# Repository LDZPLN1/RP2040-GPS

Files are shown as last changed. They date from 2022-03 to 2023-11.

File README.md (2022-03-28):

Adafruit Feather RP2040 GPS

Adafruit Feather RP2040 GPS (For HAM Radio)

UTC and local clock is set via GPS data.  Software then calculates the current Maidenhead Grid location.

DST is automatically calculated for local timezone.

Designed to get time/date/lat/lon/grid/compass direction without any internet access as a stand alone device.

ADAFRUIT FEATHER RP2040<br>
BN-880 GPS WITH MAGNETOMETER - USES U-BLOX 8 SERIES CHIPSET<br>
128X128 SSD1351 BASED OLED DISPLAY<br>
3,000 MAH LIPO BATTERY

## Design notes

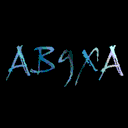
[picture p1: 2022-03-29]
images/ab9xa.bmp

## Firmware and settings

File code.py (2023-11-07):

# HAM RADIO GPS
# 2022 DOUGLAS GRAHAM, AB9XA
#
# SELF CONTAINED CLOCK, GPS, COMPASS AND ALTIMETER
# DISPLAYS TIME IN UTC AND LOCAL
# DISPLAYS CURRENT MAIDENHEAD GRID SQUARE BASED ON GPS LOCATION
#
# HARDWARE:
#
# ADAFRUIT FEATHER RP2040
# BN-880 GPS WITH MAGNETOMETER - USES U-BLOX 8 SERIES CHIPSET
# 128X128 SSD1351 BASED OLED DISPLAY
# 3,000 MAH LIPO BATTERY
#
# AVERAGE RUNTIME IS 20 HOURS
#
# NOTE: OLED DISPLAY IS NOT ADVISABLE FOR OUTDOOR/SUNLIT VIEWING
#
# PINS:
#
# A0    ANALOG INPUT TO MEASURE BATTERY VOLTAGE
# SCK   SPI CLOCK FOR DISPLAY
# MOSI  SPI DATA OUT FOR DISPLAY
# TX    UART TX FOR GPS
# RX    UART RX FOR GPS
# SDA   I2C DATA FOR MAGNETOMETER
# SCL   I2C CLOCK FOR MAGNETOMETER
# D25   DIGITAL OUTPUT - DISPLAY CHIP SELECT
# D24   DIGITAL OUTPUT - DISPLAY DATA/COMMAND
# D4    DIGITAL OUTPUT - DISPLAY RESET

import analogio
import board
import busio
import displayio
import math
import rtc
import terminalio
import time

import adafruit_fancyled.adafruit_fancyled as fancy
import adafruit_gps
import adafruit_lsm303dlh_mag

from adafruit_display_text import bitmap_label
from adafruit_progressbar.horizontalprogressbar import (HorizontalProgressBar, HorizontalFillDirection)
from adafruit_ssd1351 import SSD1351

# VERSION
version = '1.3'

################################################################
# USER ADJUSTABLE VARIABLES LISTED BELOW                       #
################################################################

# DST START / END (MONTH, WEEK, DAY, HOUR) / OFFSET IN SECONDS
dst_start = (3, 2, 6, 2)
dst_end = (11, 1, 6, 2)
dst_offset = 3600

# TIMEZONE DATA
timezone_desc = ('EST', 'EDT')
timezone_offset = -5

# MAGNETOMETER DATA
offset_x_axis = 10.6818
offset_y_axis = 1.90909
declination = -6

# MAGNETOMETER ORIENTATION
# BN-880 GPS HAS X AND Y AXIS FLIPPED (N/S E/W READINGS ARE BACKWARDS)
# BN-880 X AND Y AXIS ARE ROTATED 90 DEGREES
flip_x_axis = True
flip_y_axis = True
swap_axis = True

# STARTUP LOGO
startup_logo = '/images/ab9xa.bmp'

# TEXT COLOR SETUP
clock_color = 0x00FF00
compass_color = 0xFFFF00
date_color = 0x0000FF
gps_color = 0xFF0000
grid_color = 0xFFFF00
location_color = 0x00FF00
sat_color = 0xFF00FF

# PIN LAYOUT
pin_battery = board.A0
pin_sck = board.SCK
pin_mosi = board.MOSI
pin_rx = board.RX
pin_tx = board.TX
pin_sda = board.SDA
pin_scl = board.SCL
pin_cs = board.D25
pin_dc = board.D24
pin_rst = board.D4

# ARRAY FOR ADC VALUE TO BATTERY PERCENTAGE
bat_curve = (43300, 44000, 45000, 45700, 46000, 46600, 47500, 48800, 50000, 51400, 65535)

# BATTERY CUTOFF
bat_cutoff = 43100

# BATTERY BARGRAPH SIZE
bat_x = 16
bat_y = 8

# GPS HEARTBEAT CHARACTER
gps_char = '#'

# DISPLAY SIZE
disp_x = 128
disp_y = 128

# DISPLAY FONT DATA
font = terminalio.FONT
char_height = 10
char_start = 4
char_width = 6
line_space = 1
line_gap = 8

################################################################
# END OF USER ADJUSTABLE VARIABLES                             #
################################################################

# ARRAYS FOR DAY AND MONTH TEXT
day_text = ('MON', 'TUE', 'WED', 'THU', 'FRI', 'SAT', 'SUN')
month_text = ('JAN', 'FEB', 'MAR', 'APR', 'MAY', 'JUN', 'JUL', 'AUG', 'SEP', 'OCT', 'NOV', 'DEC')

# COMPASS DATA
comp_angle = (11.25, 33.75, 56.25, 78.75, 101.25, 123.75, 146.25, 168.75, 191.25, 213.75, 236.25, 258.75, 281.25, 303.75, 326.25, 348.75)
comp_point = ('NNE', 'NE', 'ENE', 'E', 'ESE', 'SE', 'SSE', 'S', 'SSW', 'SW', 'WSW', 'W', 'WNW', 'NW', 'NNW')

# ARRAYS FOR GRID SQUARE TEXT
grid_upper = 'ABCDEFGHIJKLMNOPQRSTUVWX'
grid_lower = 'abcdefghijklmnopqrstuvwx'

# CALCULATE AND FORMAT UTC TIME, UTC DATE, TIMEZONE TIME AND TIMEZONE DATE. CALCULATE DST
class comp_date_time:
    def __init__(self, base_time_secs):
        time_utc_tuple = time.localtime(base_time_secs)

        # CHECK FOR DEC 31 / JAN 1 OVERLAP AND CORRECT YEAR FOR TIMEZONE DATE
        base_year = time_utc_tuple[0]
        err_check_tuple = (base_year, 1, 1, 0, 0, 0, 0, 0, 0)
        err_check_secs = time.mktime(err_check_tuple) - timezone_offset * 3600

        if base_time_secs < err_check_secs:
            base_year -= 1

        # CALCULATE IN SECONDS THE DST START TIME AND DATE
        dst_start_tuple = (base_year, dst_start[0], dst_start[1] * 7 - 6, dst_start[3], 0, 0, 0, 0, 0)
        dst_start_secs = time.mktime(dst_start_tuple)
        dst_start_tuple = time.localtime(dst_start_secs)

        dst_start_diff = dst_start[2] - dst_start_tuple[6]

        if dst_start_diff < 0:
            dst_start_diff += 7

        dst_start_secs += dst_start_diff * 86400 - timezone_offset * 3600

        # CALCULATE IN SECONDS THE DST END TIME AND DATE
        dst_end_tuple = (base_year, dst_end[0], dst_end[1] * 7 - 6, dst_end[3], 0, 0, 0, 0, 0)
        dst_end_secs = time.mktime(dst_end_tuple) - dst_offset
        dst_end_tuple = time.localtime(dst_end_secs)

        dst_end_diff = dst_end[2] - dst_end_tuple[6]

        if dst_end_diff < 0:
            dst_end_diff += 7

        dst_end_secs += dst_end_diff * 86400 - timezone_offset * 3600 - dst_offset

        # IF THE CURRENT TIME AND DATE FALL BETWEEN THE DST START AND END TIMES, SET DST_ACTIVE
        if base_time_secs >= dst_start_secs and base_time_secs < dst_end_secs:
            dst_active = True
        else:
            dst_active = False

        # FORMAT UTC DATA
        self.utc_date = '{} {} {:02d}, {}'.format(day_text[time_utc_tuple[6]], month_text[time_utc_tuple[1] - 1], time_utc_tuple[2], time_utc_tuple[0])
        self.utc_time = '{:02d}:{:02d}:{:02d}'.format(time_utc_tuple[3], time_utc_tuple[4], time_utc_tuple[5])

        # CALCULATE TIMEZONE TIME AND DATE
        time_tz_secs = base_time_secs + timezone_offset * 3600 + dst_active * dst_offset
        time_tz_tuple = time.localtime(time_tz_secs)

        # FORMAT TIMEZONE DATA
        self.tz_date = '{} {} {:02d}, {}'.format(day_text[time_tz_tuple[6]], month_text[time_tz_tuple[1] - 1], time_tz_tuple[2], time_tz_tuple[0])
        self.tz_time = '{:02d}:{:02d}:{:02d}'.format(time_tz_tuple[3], time_tz_tuple[4], time_tz_tuple[5])

        self.tz_desc = timezone_desc[dst_active]

# SEND UBX MESSAGES TO GPS
# WAITS FOR ACK/NAK, RETRANSMITS ON FAILED RESPONSE
# RETURNS TRUE FOR ACK, FALSE FOR NAK
def ubx_send(msg_type, msg_class, msg_payload):
    msg_len = len(msg_class) + len(msg_payload)
    msg_base = msg_type + msg_len.to_bytes(2, 'little') + msg_class + msg_payload
    msg_out = ubx_header + msg_base + ubx_checksum(msg_base)

    msg_ackx = ubx_ack + len(msg_type).to_bytes(2, 'little') + msg_type
    msg_ack = ubx_header + msg_ackx + ubx_checksum(msg_ackx)

    msg_nakx = ubx_nak + len(msg_type).to_bytes(2, 'little') + msg_type
    msg_nak = ubx_header + msg_nakx + ubx_checksum(msg_nakx)

    while True:
        serial.reset_input_buffer()
        serial.write(msg_out)
        msg_res = serial.read(10)

        if msg_res == msg_ack:
            return True
        elif msg_res == msg_nak:
            return False
        elif msg_type == cfg_prt:
            return None

        time.sleep(0.1)

# CALCULATE CHECKSUMS FOR UBX MESSAGES
def ubx_checksum(msg):
    cs_a = 0x00
    cs_b = 0x00

    for i in range(len(msg)):
        cs_a += msg[i]
        cs_b += cs_a

    checksum = (cs_a & 255).to_bytes(1, 'big') + (cs_b & 255).to_bytes(1, 'big')
    return checksum

# CALCULATE MAIDENHEAD GRID SQUARE BASED ON CURRENT LAT / LON
def calc_grid(latitude, longitude):
    grid_lat_adj = latitude + 90
    grid_lat_sq = grid_upper[int(grid_lat_adj / 10)]
    grid_lat_field = str(int(grid_lat_adj % 10))
    grid_lat_rem = (grid_lat_adj - int(grid_lat_adj)) * 60
    grid_lat_subsq = grid_lower[int(grid_lat_rem / 2.5)]

    grid_lon_adj = longitude + 180
    grid_lon_sq = grid_upper[int(grid_lon_adj / 20)]
    grid_lon_field = str(int((grid_lon_adj/2) % 10))
    grid_lon_rem = (grid_lon_adj - int(grid_lon_adj / 2) * 2) * 60
    grid_lon_subsq = grid_lower[int(grid_lon_rem / 5)]

    return grid_lon_sq + grid_lat_sq + grid_lon_field + grid_lat_field + grid_lon_subsq + grid_lat_subsq

# CALCULATE ANGLE FROM MAGNETOMETER DATA
def comp_degree(x_axis, y_axis):
    x_axis -= offset_x_axis
    y_axis -= offset_y_axis

    if flip_x_axis:
        x_axis *= -1

    if flip_y_axis:
        y_axis *= -1

    if swap_axis:
        x_axis, y_axis = y_axis, x_axis

    if (x_axis > 0) and (y_axis == 0):
        angle = declination
    elif (x_axis < 0) and (y_axis == 0):
        angle = 180 + declination
    elif y_axis > 0:
        angle = 90 - math.atan(x_axis/y_axis) * 180 / math.pi + declination
    elif y_axis < 0:
        angle = 270 - math.atan(x_axis/y_axis) * 180 / math.pi + declination

    if angle < 0:
        angle += 360

    if angle >= 360:
        angle -= 360

    return angle

# CALCULATE COMPASS DIRECTION FROM ANGLE
def comp_direction(degrees):
    if degrees == -1:
        direction = '---'
    elif (degrees < 11.25) or (degrees >= 348.75):
        direction = 'N'
    else:
        for i in range(15):
            c_angle = comp_angle[i]

            if (degrees >= c_angle) and (degrees < (c_angle + 22.5)):
                direction = comp_point[i]
                break

    return direction

# CALCULATE BATTERY PERCENTAGE
def bat_level(adc_value):
    bat_percent = 0

    for percent in range(10, 1, -1):
        if adc_value <= bat_curve[percent] and adc_value > bat_curve[percent - 1]:
            bat_percent = percent * 10
            break

    return bat_percent

# SETUP CLOCK
clock = rtc.RTC()

# SETUP OLED DISPLAY
displayio.release_displays()
spi = busio.SPI(pin_sck, MOSI=pin_mosi)
disp_bus = displayio.FourWire(spi, command=pin_dc, chip_select=pin_cs, reset=pin_rst, baudrate=60000000)
disp = SSD1351(disp_bus, width=disp_x, height=disp_y)

# SETUP MAGNETOMETER
i2c = busio.I2C(pin_scl, pin_sda)
comp = adafruit_lsm303dlh_mag.LSM303DLH_Mag(i2c)

# SETUP ADC FOR BATTERY MONITORING
bat = analogio.AnalogIn(pin_battery)

# DISPLAY SPLASH LOGO
bitmap = displayio.OnDiskBitmap(startup_logo)
tile_grid = displayio.TileGrid(bitmap, pixel_shader=bitmap.pixel_shader)
disp_group = displayio.Group()
disp_group.append(tile_grid)
disp.show(disp_group)

# CREATE COLOR GRADIENT AND PALETTE FOR BATTERY GAUGE
bat_gradient = [(0.0, 0xFF0000), (0.25, 0xFF7F00), (0.50, 0xFFFF00), (0.75, 0x00FF00)]
bat_palette = fancy.expand_gradient(bat_gradient, 100)
bat_colors = []

for i in range(100):
    color = fancy.palette_lookup(bat_palette, i / 100)
    bat_colors.append(color.pack())

# REMOVE SPLASH LOGO
time.sleep(1.5)
disp_group.remove(tile_grid)

# DISPLAY VERSION
message_text = 'Version ' + version
message_x = int((disp_x - len(message_text) * char_width) / 2)
message_text = bitmap_label.Label(font, text=message_text, color=0xFFB000, x=message_x, y=int(disp_y / 2))
disp_group.append(message_text)
time.sleep(1.0)
disp_group.remove(message_text)

# CONFIGURE GPS
message_text = ('Configuring GPS')
message_x = int((disp_x - len(message_text) * char_width) / 2)
message_text = bitmap_label.Label(font, text=message_text, color=0x00FFFF, x=message_x, y=int(disp_y / 2))
disp_group.append(message_text)

# UBX HEADER
ubx_header = bytes([0xb5, 0x62])

# UBX ACK/NAK
ubx_ack = bytes([0x05, 0x01])
ubx_nak = bytes([0x05, 0x00])

# UBX MESSAGE TYPES
cfg_prt = bytes([0x06, 0x00])
cfg_msg = bytes([0x06, 0x01])

# UBX CLASS IDS
cls_gll = bytes([0xF0, 0x01])
cls_gsa = bytes([0xF0, 0x02])
cls_gsv = bytes([0xF0, 0x03])
cls_vtg = bytes([0xF0, 0x05])

# CONFIGURE UART AND GPS BAUD RATE
serial = busio.UART(pin_tx, pin_rx, baudrate=38400, timeout=1, receiver_buffer_size=256)

# DISABLE NMEA GLL, GSA, GSV AND VTG MESSAGES, ONLY RMC AND GGA ARE NEEDED
# ENABLING MORE MESSAGES THAN NEEDED CAN CAUSE SERIAL BUFFER OVERRUNS AND DEVICE LOCKUPS
payload = bytes([0x00, 0x00, 0x00, 0x00, 0x00, 0x00])

while not ubx_send(cfg_msg, cls_gll, payload):
    time.sleep(.1)

while not ubx_send(cfg_msg, cls_gsa, payload):
    time.sleep(.1)

while not ubx_send(cfg_msg, cls_gsv, payload):
    time.sleep(.1)

while not ubx_send(cfg_msg, cls_vtg, payload):
    time.sleep(0.1)

disp_group.remove(message_text)

# CONFIGURE GPS
message_text = ('Waiting for GPS Fix')
message_x = int((disp_x - len(message_text) * char_width) / 2)
message_text = bitmap_label.Label(font, text=message_text, color=0x00FFFF, x=message_x, y=int(disp_y / 2))
disp_group.append(message_text)

timer_start_gps = time.monotonic()
counter_text = '00:00'
counter_x = int((disp_x - len(counter_text) * char_width) / 2)
counter_text = bitmap_label.Label(font, text=counter_text, color=0xFFFFFF, x=counter_x, y=int(disp_y / 2) + char_height + 2)
disp_group.append(counter_text)

# SETUP GPS DECODING
gps = adafruit_gps.GPS(serial, debug=False)

# WAIT FOR INITIAL GPS FIX
old_counter = -1

while not gps.has_fix:
    gps.update()
    counter_gps = time.monotonic() - timer_start_gps
    counter_min = int(counter_gps / 60)
    counter_sec = int(counter_gps % 60)

    if old_counter != counter_sec:
        old_counter = counter_sec
        counter_text.text = '{:02d}:{:02d}'.format(counter_min, counter_sec)

    time.sleep(0.2)

disp_group.remove(message_text)

serial.reset_input_buffer()

message_text = ('Waiting For Time Sync')
message_x = int((disp_x - len(message_text) * char_width) / 2)
message_text = bitmap_label.Label(font, text=message_text, color=0x00FFFF, x=message_x, y=int(disp_y / 2))
disp_group.append(message_text)

# WAIT FOR VALID TIME DATA TO SET RTC
while True:
    if gps.timestamp_utc.tm_year != 0:
        break

    gps.update()
    counter_gps = time.monotonic() - timer_start_gps
    counter_min = int(counter_gps / 60)
    counter_sec = int(counter_gps % 60)
    counter_text.text = '{:02d}:{:02d}'.format(counter_min, counter_sec)
    time.sleep(0.5)

# SET RTC TO GPS TIME (GPS REFERENCES UTC)
clock.datetime = time.struct_time((gps.timestamp_utc.tm_year, gps.timestamp_utc.tm_mon, gps.timestamp_utc.tm_mday, gps.timestamp_utc.tm_hour, gps.timestamp_utc.tm_min, gps.timestamp_utc.tm_sec, 0, -1, -1))
rtc.set_time_source(gps)
disp_group.remove(counter_text)
disp_group.remove(message_text)

# DISPLAY BATTERY GAUGE
bat_progress_bar = HorizontalProgressBar((disp_x - bat_x, 0), (bat_x, bat_y), value=0, min_value=0, max_value=100, fill_color=0x000000, outline_color=0xFFFFFF, bar_color=0x00FF00, direction=HorizontalFillDirection.LEFT_TO_RIGHT)
disp_group.append(bat_progress_bar)

# DISPLAY TIME AND DATE FIELDS
utc_clock_text = bitmap_label.Label(font, text=' '*8, color=clock_color, x=0, y=char_start)
disp_group.append(utc_clock_text)

utc_clock_label = bitmap_label.Label(font, text='UTC', color=clock_color, x=char_width * 9, y=char_start)
disp_group.append(utc_clock_label)

utc_date_text = bitmap_label.Label(font, text=' '*16, color=date_color, x=0, y=char_start + char_height + line_space)
disp_group.append(utc_date_text)

tz_clock_text = bitmap_label.Label(font, text=' '*8, color=clock_color, x=0, y=char_start + (char_height + line_space) * 2 + line_gap)
disp_group.append(tz_clock_text)

tz_clock_label = bitmap_label.Label(font, text='   ', color=clock_color, x=char_width * 9, y=char_start + (char_height + line_space) * 2 + line_gap)
disp_group.append(tz_clock_label)

tz_date_text = bitmap_label.Label(font, text=' '*16, color=date_color, x=0, y=char_start + (char_height + line_space) * 3 + line_gap)
disp_group.append(tz_date_text)

# DISPLAY LATITUDE / LONGITUDE / ALTITUDE / GRID / COMPASS FIELDS
lat_label = bitmap_label.Label(font, text='Lat:', color=location_color, x=0, y=char_start + (char_height + line_space) * 4 + line_gap * 2)
disp_group.append(lat_label)

lat_text = bitmap_label.Label(font, text=' '*8, color=location_color, x=char_width * 6, y=char_start + (char_height + line_space) * 4 + line_gap * 2)
disp_group.append(lat_text)

grid_text = bitmap_label.Label(font, text=' '*6, color=grid_color, x=char_width * 15, y=char_start + (char_height + line_space) * 4 + line_gap * 2)
disp_group.append(grid_text)

lon_label = bitmap_label.Label(font, text='Lon:', color=location_color, x=0, y=char_start + (char_height + line_space) * 5 + line_gap * 2)
disp_group.append(lon_label)

lon_text = bitmap_label.Label(font, text=' '*9, color=location_color, x=char_width * 5, y=char_start + (char_height + line_space) * 5 + line_gap * 2)
disp_group.append(lon_text)

gps_update_text = bitmap_label.Label(font, text=' ', color=gps_color, x=char_width * 20, y=char_start + (char_height + line_space) * 5 + line_gap * 2)
disp_group.append(gps_update_text)

# DISPLAY GPS STATISTICS
alt_label = bitmap_label.Label(font, text='Alt:', color=location_color, x=0, y=char_start + (char_height + line_space) * 6 + line_gap * 3)
disp_group.append(alt_label)

alt_ft_text = bitmap_label.Label(font, text=' '*5, color=location_color, x=char_width * 5, y=char_start + (char_height + line_space) * 6 + line_gap * 3)
disp_group.append(alt_ft_text)

alt_ft_label = bitmap_label.Label(font, text='FT', color=location_color, x=char_width * 11, y=char_start + (char_height + line_space) * 6 + line_gap * 3)
disp_group.append(alt_ft_label)

alt_m_text = bitmap_label.Label(font, text=' '*5, color=location_color, x=char_width * 14, y=char_start + (char_height + line_space) * 6 + line_gap * 3)
disp_group.append(alt_m_text)

alt_m_label = bitmap_label.Label(font, text='M', color=location_color, x=char_width * 20, y=char_start + (char_height + line_space) * 6 + line_gap * 3)
disp_group.append(alt_m_label)

speed_label = bitmap_label.Label(font, text='Spd:', color=location_color, x=0, y=char_start + (char_height + line_space) * 7 + line_gap * 3)
disp_group.append(speed_label)

speed_text = bitmap_label.Label(font, text=' '*5, color=location_color, x=char_width * 5, y=char_start + (char_height + line_space) * 7 + line_gap * 3)
disp_group.append(speed_text)

track_label = bitmap_label.Label(font, text='Trk:', color=location_color, x=char_width * 11, y=char_start + (char_height + line_space) * 7 + line_gap * 3)
disp_group.append(track_label)

track_text = bitmap_label.Label(font, text=' '*5, color=location_color, x=char_width * 16, y=char_start + (char_height + line_space) * 7 + line_gap * 3)
disp_group.append(track_text)

sat_count_label = bitmap_label.Label(font, text='Satellites:', color=sat_color, x=0, y=char_start + (char_height + line_space) * 8 + line_gap * 4)
disp_group.append(sat_count_label)

sat_count_text = bitmap_label.Label(font, text='  ', color=sat_color, x=char_width * 12, y=char_start + (char_height + line_space) * 8 + line_gap * 4)
disp_group.append(sat_count_text)

comp_text = bitmap_label.Label(font, text='   ', color=compass_color, x=char_width * 18, y=char_start + (char_height + line_space) * 8 + line_gap * 4)
disp_group.append(comp_text)
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

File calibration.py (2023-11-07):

import board
import displayio
import math
import terminalio
import time

import adafruit_lsm303dlh_mag

from adafruit_display_text import label
from adafruit_ssd1351 import SSD1351

flip_x_axis = True
flip_y_axis = True
swap_axis = True

def comp_degree(x_axis, y_axis):
    if flip_x_axis:
        x_axis *= -1

    if flip_y_axis:
        y_axis *= -1

    if swap_axis:
        x_axis, y_axis = y_axis, x_axis

    if (x_axis > 0) and (y_axis == 0):
        angle = 0
    elif (x_axis < 0) and (y_axis == 0):
        angle = 180
    elif y_axis > 0:
        angle = 90 - math.atan(x_axis/y_axis) * 180 / math.pi
    elif y_axis < 0:
        angle = 270 - math.atan(x_axis/y_axis) * 180 / math.pi

    if angle < 0:
        angle += 360

    if angle >= 360:
        angle -= 360

    return angle

def comp_direction(degrees):
    if degrees == -1:
        direction = '---'
    elif (degrees < 11.25) or (degrees >= 348.75):
        direction = 'N'
    else:
        for i in range(15):
            c_angle = comp_angle[i]

            if (degrees >= c_angle) and (degrees < (c_angle + 22.5)):
                direction = comp_point[i]
                break

    return direction

displayio.release_displays()
spi = board.SPI()
disp_bus = displayio.FourWire(spi, command=board.D24, chip_select=board.D25, reset=board.D4, baudrate=18000000)
disp = SSD1351(disp_bus, width=128, height=128)

i2c = board.I2C()
comp = adafruit_lsm303dlh_mag.LSM303DLH_Mag(i2c)

# DISPLAY SPLASH LOGO
bitmap = displayio.OnDiskBitmap('/images/ab9xa.bmp')
tile_grid = displayio.TileGrid(bitmap, pixel_shader=bitmap.pixel_shader)
disp_group = displayio.Group()
disp_group.append(tile_grid)
disp.show(disp_group)

comp_angle = (11.25, 33.75, 56.25, 78.75, 101.25, 123.75, 146.25, 168.75, 191.25, 213.75, 236.25, 258.75, 281.25, 303.75, 326.25, 348.75)
comp_point = ('NNE', 'NE', 'ENE', 'E', 'ESE', 'SE', 'SSE', 'S', 'SSW', 'SW', 'WSW', 'W', 'WNW', 'NW', 'NNW')

font = terminalio.FONT

# REMOVE SPLASH LOGO
time.sleep(1.5)
disp_group.remove(tile_grid)

angle_text = label.Label(font, text='      ', color=0xFFFFFF, x=0, y=3)
disp_group.append(angle_text)

direction_text = label.Label(font, text='   ', color=0xFFFFFF, x=111, y=3)
disp_group.append(direction_text)

corrected_angle_text = label.Label(font, text='      ', color=0xFFFFFF, x=0, y=14)
disp_group.append(corrected_angle_text)

corrected_direction_text = label.Label(font, text='   ', color=0xFFFFFF, x=111, y=14)
disp_group.append(corrected_direction_text)

x_raw_text = label.Label(font, text='         ', color=0xFFFFFF, x=0, y=30)
disp_group.append(x_raw_text)

y_raw_text = label.Label(font, text='         ', color=0xFFFFFF, x=0, y=41)
disp_group.append(y_raw_text)

x_cal_text = label.Label(font, text='         ', color=0xFFFFFF, x=0, y=57)
disp_group.append(x_cal_text)

y_cal_text = label.Label(font, text='         ', color=0xFFFFFF, x=0, y=68)
disp_group.append(y_cal_text)

def main():
    x_min = 0
    x_max = 0
    y_min = 0
    y_max = 0

    while True:
        x, y, _ = comp.magnetic

        if x < x_min:
            x_min = x

        if x > x_max:
            x_max = x

        if y < y_min:
            y_min = y

        if y > y_max:
            y_max = y

        x_cal = (x_min + x_max) / 2
        y_cal = (y_min + y_max) / 2

        corrected_x = x - x_cal
        corrected_y = y - y_cal

        uncorrected_angle = comp_degree(x, y)
        uncorrected_direction = comp_direction(uncorrected_angle)
        corrected_angle = comp_degree(corrected_x, corrected_y)
        corrected_direction = comp_direction(corrected_angle)

        angle_text.text = str(uncorrected_angle)
        direction_text.text = uncorrected_direction
        corrected_angle_text.text = str(corrected_angle)
        corrected_direction_text.text = corrected_direction
        x_raw_text.text = str(x)
        y_raw_text.text = str(y)
        x_cal_text.text = str(x_cal)
        y_cal_text.text = str(y_cal)

main()

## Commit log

2022-03-17 Add files via upload
    Schematic
    [RP2040 GPS.kicad_sch]
2022-03-18 Moved Nav Label code and updated SPI clock rate
2022-03-23 Replace label with bitmap_label to conserve memory
    [code.py]
2022-03-28 Layout Update
    [RP2040 GPS.kicad_sch]
2022-03-28 Fix math in class comp_date_time
    [code.py]
2022-03-29 Updated Low Battery message display
2022-03-29 Magnetometer calibration
2023-11-07 Minor fix for 8.x display library
    [code.py]
